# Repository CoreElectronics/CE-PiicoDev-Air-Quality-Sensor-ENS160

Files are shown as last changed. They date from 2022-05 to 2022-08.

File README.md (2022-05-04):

# PiicoDev® Air Quality Sensor ENS160

<!-- TODO update link URL with CE SKU -->
<!-- TODO update link title -->
<!-- TODO put image in Documents directory. Piicodev image 1500x1000 resize to 30% -> 450x300 -->


This is the hardware repo for the Core Electronics [PiicoDev Air Quality Sensor ENS160](https://core-electronics.com.au/catalog/product/view/sku/CE08560).

<!-- TODO populate below here from the tutorial -->

## License
This project is open source - please review the LICENSE.md file for further licensing information.

If you have any technical questions, or concerns about licensing, please contact technical support on the [Core Electronics forums](https://forum.core-electronics.com.au/).

## Attribution
<!-- TODO Confirm attribution eg
The hardware design of this module is influenced by the design from [Sparkfun](https://github.com/sparkfun/Qwiic_Capacitive_Touch_Slider_CAP1203).  -->

*\"PiicoDev\" and the PiicoDev logo are trademarks of Core Electronics Pty Ltd.*

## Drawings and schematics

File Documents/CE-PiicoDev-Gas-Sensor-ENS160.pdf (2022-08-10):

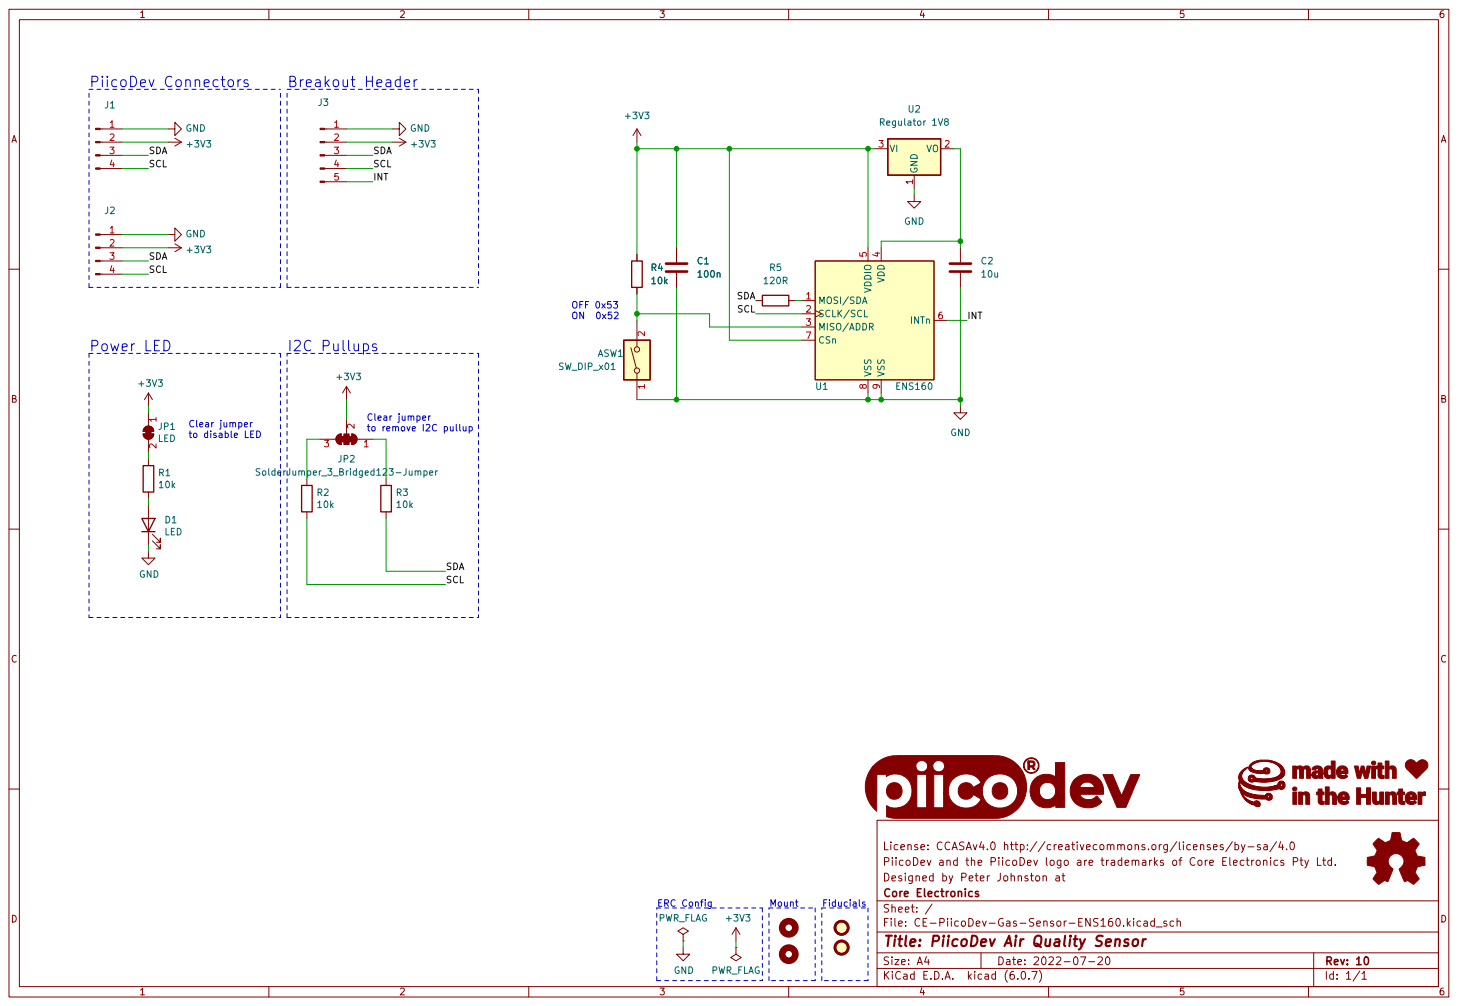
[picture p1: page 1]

1 VO 2 VI 3 U2 Regulator 1V8 GND

License: CCASAv4.0 http://creativecommons.org/licenses/by-sa/4.0
PiicoDev and the PiicoDev logo are trademarks of Core Electronics Pty Ltd.
File: CE-PiicoDev-Gas-Sensor-ENS160.kicad_sch Sheet: / Core Electronics Designed by Peter Johnston at

Id: 1/1 Title: PiicoDev Air Quality Sensor

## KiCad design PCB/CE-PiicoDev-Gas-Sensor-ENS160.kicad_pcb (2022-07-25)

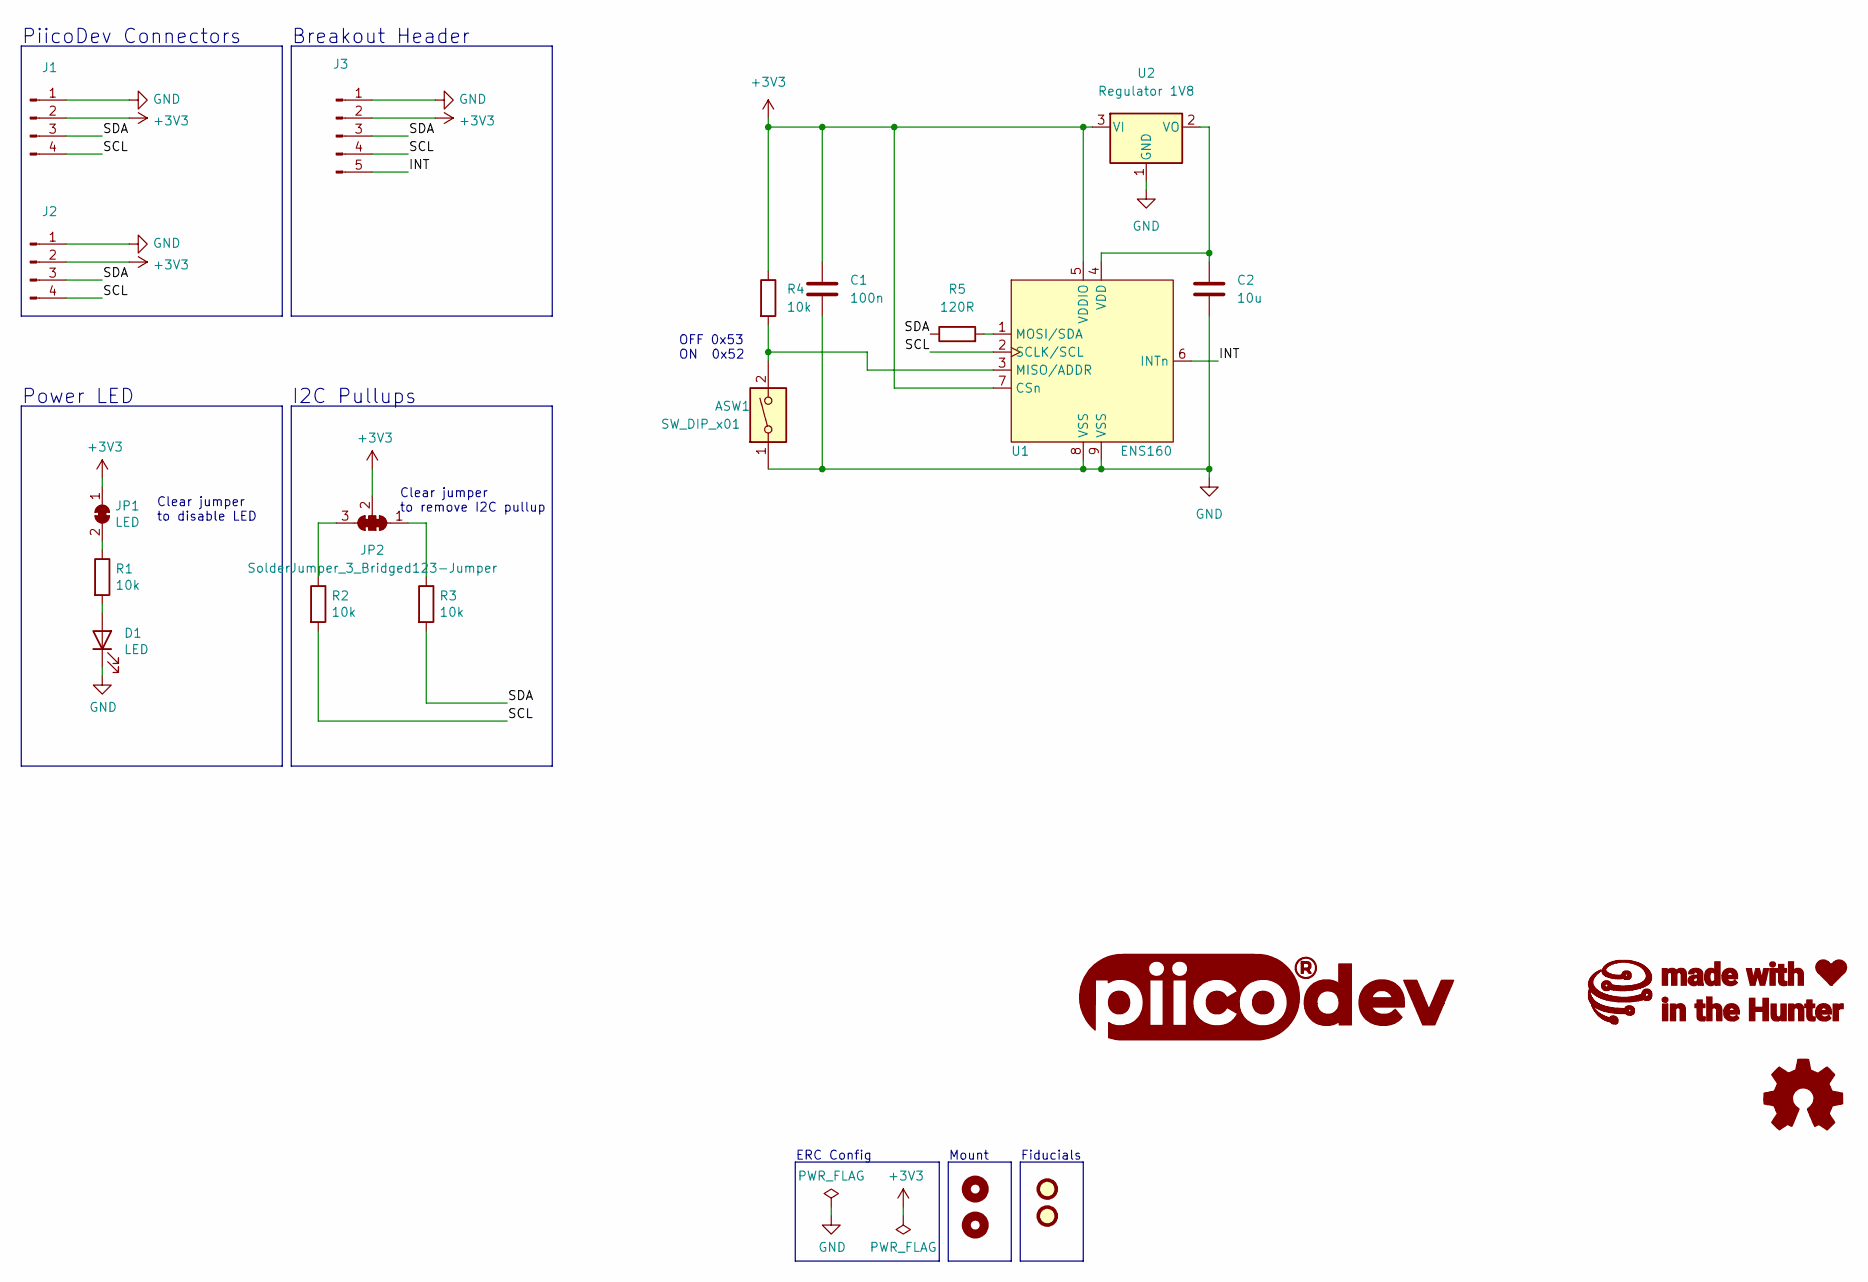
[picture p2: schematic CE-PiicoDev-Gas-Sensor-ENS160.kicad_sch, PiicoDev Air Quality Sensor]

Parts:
ASW1: SW_DIP_x01; SW_DIP_x01_Slide_CHS-01A1
C1: 100n; C_0402_1005Metric
C2: 10u; C_0603_1608Metric
D1: LED; LED_0603_1608Metric
FID1, FID2: Fiducial; Fiducial_1mm_Mask2mm
G1: LOGO_PiicoDev; piicodev_logo_14.2x3.4mm
G2: LOGO_CoreElectronics_no-text; CoreElectronics_logo_5mm
G3: LOGO_made-with-love; piicodev_logo_14.2x3.4mm
H1, H2: MountingHole; MountingHole_2.7mm_M2.5_PadClearance_1.2
J1, J2: JST_SH_SM04B-SRSS-TB_1x04-1MP_P1.00mm_Horizontal
J3: Conn_01x05_Male; PiicoDev_header_5pin
JP1: LED; SolderJumper-2_P1.3mm_Bridged_RoundedPad1.0x1.5mm
JP2: SolderJumper_3_Bridged123-Jumper; SolderJumper-3_P1.3mm_Closed_RoundedPad1.0x1.5mm_NumberLabe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
LOGO1: Logo_Open_Hardware_Small; oshw
R1, R2, R3, R4: 10k; R_0402_1005Metric
R5: 120R; R_0402_1005Metric
U1: ENS160; ScioSense_ENS160
U2: Regulator 1V8; SOT-23

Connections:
+3V3: C1.1, J1.2, J2.2, J3.2, JP1.1 (A), JP2.2 (C), R4.1, U1.5 (VDDIO), U1.7 (CSn), U2.3 (VI)
/INT: J3.5, U1.6 (INTn)
/SCL: J1.4, J2.4, J3.4, R2.2, U1.2 (SCLK/SCL)
/SDA: J1.3, J2.3, J3.3, R3.2, R5.1
GND: ASW1.1, C1.2, C2.2, D1.1 (K), J1.1, J2.1, J3.1, U1.8 (VSS), U1.9 (VSS), U2.1 (GND)
unnamed: C2.1, U1.4 (VDD), U2.2 (VO)
unnamed: D1.2 (A), R1.2
unnamed: JP1.2 (B), R1.1
unnamed: JP2.1 (A), R3.1
unnamed: JP2.3 (B), R2.1
unnamed: R5.2, U1.1 (MOSI/SDA)
unnamed: ASW1.2, R4.2, U1.3 (MISO/ADDR)

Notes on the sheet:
Breakout Header
Fiducials
I2C Pullups
Clear jumper to remove I2C pullup
ERC Config
OFF 0x53 ON 0x52
Power LED
Clear jumper to disable LED
Mount
PiicoDev Connectors

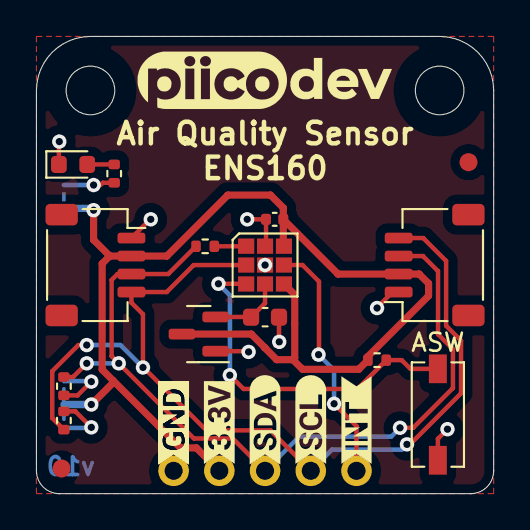
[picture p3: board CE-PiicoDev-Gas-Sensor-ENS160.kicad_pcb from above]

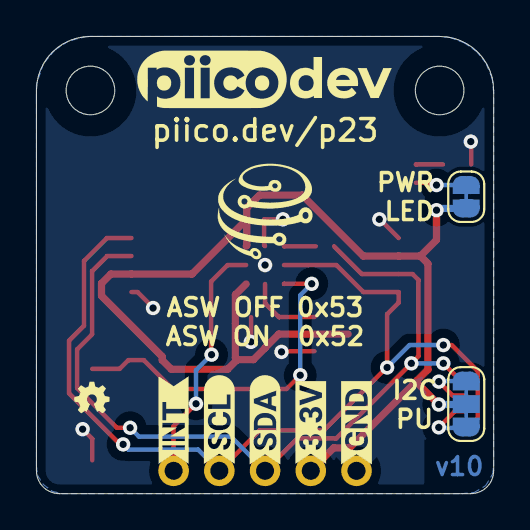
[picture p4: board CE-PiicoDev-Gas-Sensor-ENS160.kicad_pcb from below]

Board: 2 copper layers, 25.4 x 25.4 mm, 35 parts (10 on the bottom side), 12 nets.

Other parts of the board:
kibuzzard-6285E79D, kibuzzard-6285E79D#2: G***; kibuzzard-6285E79D
kibuzzard-6285E559, kibuzzard-6285E559#2: G***; kibuzzard-6285E559
kibuzzard-6285E568, kibuzzard-6285E568#2: G***; kibuzzard-6285E568
kibuzzard-6285E695, kibuzzard-6285E695#2, kibuzzard-6285E695#3: G***; kibuzzard-6285E695
kibuzzard-6285E748, kibuzzard-6285E748#2: G***; kibuzzard-6285E748

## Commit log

2022-05-04 Add PCB
    [CE-PiicoDev-Gas-Sensor-ENS160.kicad_pcb, CE-PiicoDev-Gas-Sensor-ENS160.kicad_sch]
2022-06-21 Change default I2C address
    [CE-PiicoDev-Gas-Sensor-ENS160.kicad_pcb, CE-PiicoDev-Gas-Sensor-ENS160.kicad_sch]
2022-07-25 v10 release
    [CE-PiicoDev-Gas-Sensor-ENS160.kicad_pcb, CE-PiicoDev-Gas-Sensor-ENS160.kicad_sch]
